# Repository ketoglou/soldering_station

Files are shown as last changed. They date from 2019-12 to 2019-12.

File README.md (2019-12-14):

# Soldering_station
A personal soldering station for Hakko 907 in Greek language but it can be easily adapted to any language.\
The following image shows the Temperature(red line) vs Resistance(blue line) chart of Hakko 907.\
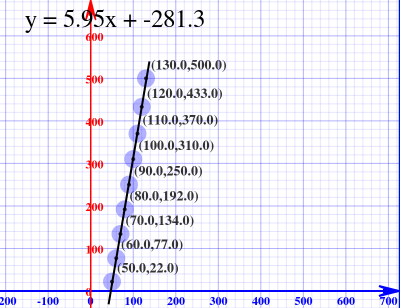
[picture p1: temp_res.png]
 \
The equation that is used to calculate temperature is based in least squares method and \
it is the following : Temperature = 5.95 * Resistance - 281.3.

- PCB.zip : Contains gerber files for PCB.
- Firmware : Contains PIC18F27K42 firmware.

The following image shows the PCB.\
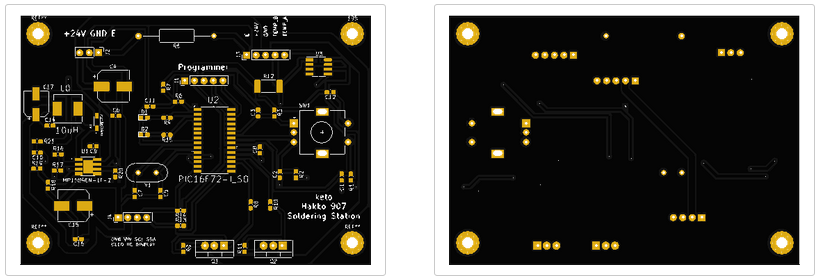
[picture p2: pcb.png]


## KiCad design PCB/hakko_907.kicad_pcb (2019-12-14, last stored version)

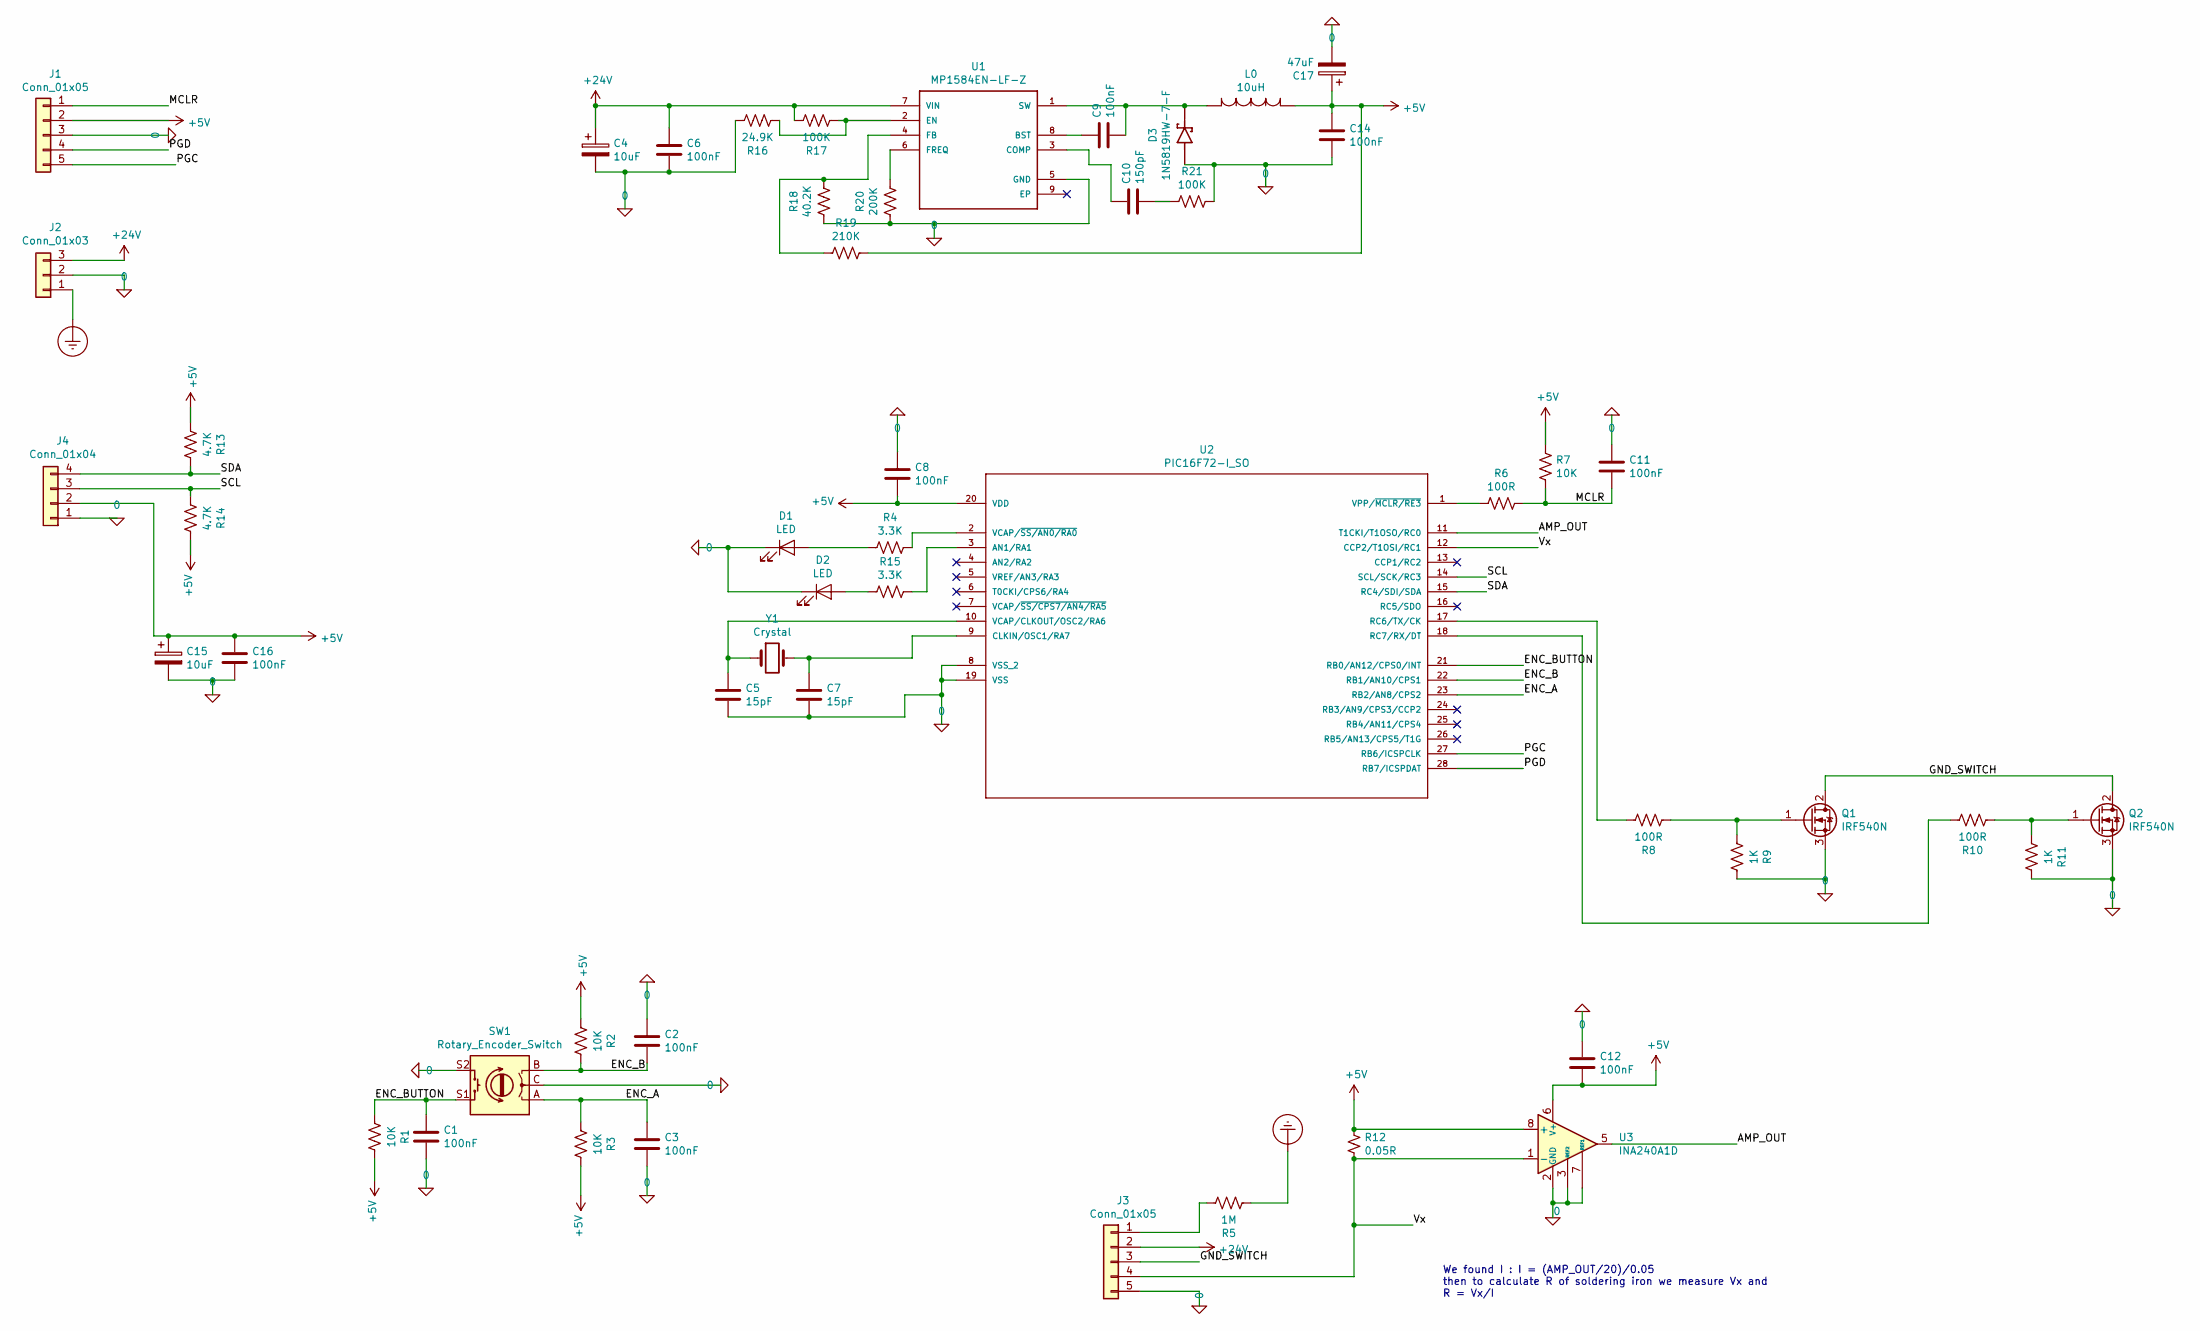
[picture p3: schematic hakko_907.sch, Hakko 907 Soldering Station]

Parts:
C1, C2, C3, C6, C8, C9, C11, C12, C14, C16: 100nF; C_0603_1608Metric_Pad1.05x0.95mm_HandSolder
C4, C15: 10uF; CP_Elec_8x6.2
C5, C7: 15pF; C_0603_1608Metric_Pad1.05x0.95mm_HandSolder
C10: 150pF; C_0603_1608Metric_Pad1.05x0.95mm_HandSolder
C17: 47uF; CP_Elec_6.3x5.9
D1, D2: LED; LED_0603_1608Metric_Pad1.05x0.95mm_HandSolder
D3: 1N5819HW-7-F; SOD3715X145N
J1, J3: Conn_01x05; PinHeader_1x05_P2.54mm_Vertical
J2: Conn_01x03; PinHeader_1x03_P2.54mm_Vertical
J4: Conn_01x04; PinHeader_1x04_P2.54mm_Vertical
L0: 10uH; INDM7676X355N
Q1, Q2: IRF540N; TO-220-3_Vertical
R1, R2, R3, R7: 10K; R_0603_1608Metric_Pad1.05x0.95mm_HandSolder
R4, R15: 3.3K; R_0603_1608Metric_Pad1.05x0.95mm_HandSolder
R5: 1M; R_Axial_DIN0309_L9.0mm_D3.2mm_P20.32mm_Horizontal
R6, R8, R10: 100R; R_0603_1608Metric_Pad1.05x0.95mm_HandSolder
R9, R11: 1K; R_0603_1608Metric_Pad1.05x0.95mm_HandSolder
R12: 0.05R; R_2512_6332Metric_Pad1.52x3.35mm_HandSolder
R13, R14: 4.7K; R_0603_1608Metric_Pad1.05x0.95mm_HandSolder
R16: 24.9K; R_0603_1608Metric_Pad1.05x0.95mm_HandSolder
R17, R21: 100K; R_0603_1608Metric_Pad1.05x0.95mm_HandSolder
R18: 40.2K; R_0603_1608Metric_Pad1.05x0.95mm_HandSolder
R19: 210K; R_0603_1608Metric_Pad1.05x0.95mm_HandSolder
R20: 200K; R_0603_1608Metric_Pad1.05x0.95mm_HandSolder
SW1: Rotary_Encoder_Switch; RotaryEncoder_Alps_EC11E-Switch_Vertical_H20mm
U1: MP1584EN-LF-Z; SOIC127P600X170-9N
U2: PIC16F72-I_SO; SOIC127P1030X265-28N
U3: INA240A1D; SOIC-8_3.9x4.9mm_P1.27mm
Y1: Crystal; Crystal_HC49-4H_Vertical

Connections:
0: C1.2, C2.1, C3.2, C4.2, C5.2, C6.2, C7.2, C8.1, C11.1, C12.1, C14.2, C15.2, C16.2, C17.2, D1.1 (K), D2.1 (K), D3.A, J1.3, J2.2, J3.5, J4.1, Q1.3 (S), Q2.3 (S), R9.1, R11.1, R16.1, R18.2, R20.2, R21.1, SW1.C, SW1.S2, U1.5 (GND), U2.8 (VSS_2), U2.19 (VSS), U3.2 (GND), U3.3 (REF2), U3.4 (GND), U3.7 (REF1)
+5V: C8.2, C12.2, C14.1, C15.1, C16.1, C17.1, J1.2, J4.2, L0.1, R1.1, R2.2, R3.1, R7.1, R12.1, R13.2, R14.1, R19.1, U2.20 (VDD), U3.6 (V+), U3.8 (+)
+24V: C4.1, C6.1, J2.3, J3.2, R17.1, U1.7 (VIN)
/AMP_OUT: U2.11 (T1CKI/T1OSO/RC0), U3.5
/ENC_A: C3.1, R3.2, SW1.A, U2.23 (RB2/AN8/CPS2)
/ENC_B: C2.2, R2.1, SW1.B, U2.22 (RB1/AN10/CPS1)
/ENC_BUTTON: C1.1, R1.2, SW1.S1, U2.21 (RB0/AN12/CPS0/INT)
/GND_SWITCH: J3.3, Q1.2 (D), Q2.2 (D)
/MCLR: C11.2, J1.1, R6.1, R7.2
/PGC: J1.5, U2.27 (RB6/ICSPCLK)
/PGD: J1.4, U2.28 (RB7/ICSPDAT)
/SCL: J4.3, R14.2, U2.14 (SCL/SCK/RC3)
/SDA: J4.4, R13.1, U2.15 (RC4/SDI/SDA)
/Vx: J3.4, R12.2, U2.12 (CCP2/T1OSI/RC1), U3.1 (-)
Earth_Protective: J2.1, R5.2
unnamed: C5.1, U2.10 (VCAP/CLKOUT/OSC2/RA6), Y1.1
unnamed: C7.1, U2.9 (CLKIN/OSC1/RA7), Y1.2
unnamed: C9.1, U1.8 (BST)
unnamed: C9.2, D3.C (K), L0.2, U1.1 (SW)
unnamed: C10.1, U1.3 (COMP)
unnamed: C10.2, R21.2
unnamed: D1.2 (A), R4.2
unnamed: D2.2 (A), R15.2
unnamed: J3.1, R5.1
unnamed: Q1.1 (G), R8.2, R9.2
unnamed: Q2.1 (G), R10.2, R11.2
unnamed: R4.1, U2.2 (VCAP/~SS/AN0/RA0)
unnamed: R6.2, U2.1 (VPP/~MCLR/RE3)
unnamed: R8.1, U2.17 (RC6/TX/CK)
unnamed: R10.1, U2.18 (RC7/RX/DT)
unnamed: R15.1, U2.3 (AN1/RA1)
unnamed: R16.2, R17.2, U1.2 (EN)
unnamed: R18.1, R19.2, U1.4 (FB)
unnamed: R20.1, U1.6 (FREQ)

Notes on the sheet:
We found I : I = (AMP_OUT/20)/0.05 then to calculate R of soldering iron we measure Vx and R = Vx/I

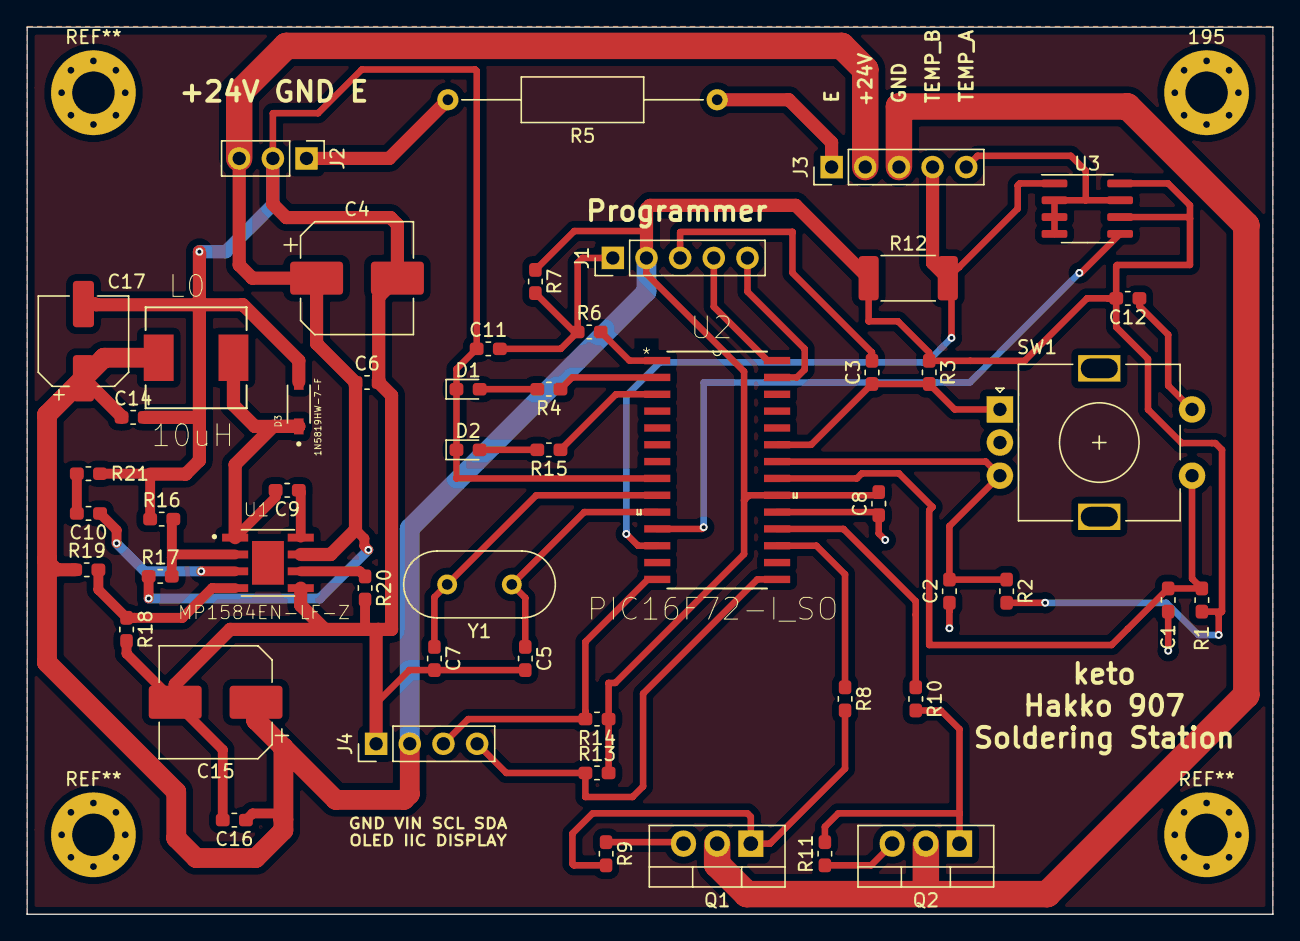
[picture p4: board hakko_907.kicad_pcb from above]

Board: 2 copper layers, 94.0 x 66.9 mm, 53 parts (0 on the bottom side), 34 nets.

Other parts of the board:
195: MountingHole_3.2mm_M3_Pad_Via

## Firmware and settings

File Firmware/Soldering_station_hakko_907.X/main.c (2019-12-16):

/*
 * File:   main.c
 * Author: orion
 *
 * Created on October 25, 2019, 9:03 PM
 */

/* EEPROM:
 * ADDRESS: 0                   1
 * DATA   : HIGH_BYTE_OLD_TEMP  LOW_BYTE_OLD_TEMP
 */

//Includes
#include <xc.h>
#include <pic18f27k42.h>
#include "config.h"
#include "i2c.h"
#include "oled_sdd1306.h"
#include "init_strings.h"

// This code is meant to run on a PIC running at 64 MHz.
#define _XTAL_FREQ 64000000
#define byte unsigned char
#define LED_STAT LATAbits.LA0
#define LED_READY LATAbits.LA1
#define MOSFET1 LATCbits.LC6
#define MOSFET2 LATCbits.LC7

//Define functions
void timer0_init(void);
void external_interrupt_init(void);
void write_eeprom(byte data,byte address[2]); //address[0]=high byte of address,address[1]=low byte of address
byte read_eeprom(byte address[2]);
void timer2PWM_init(void);
void ADC_Init(void);
void ADC_Start(byte pin);

//Define variables
int seconds_passed;
//byte max6675_read; //MAX6675 could not be expected to produce more than about 5 reads per second.
int set_temp = 180;
byte set_temperature[3];
byte real_temperature[3];
byte temp_change = 1;
int old_temp = 0;
byte eeprom_address[2];
int real_temp = 0;
int temporary_val; //temporary value
float dV,dV_average,Current,Vx,Vx_average,R,Temp;
byte measure_flag = 0;
byte timer2_pwm_counter = 0;
byte pulse_width;
int adc_result;
byte adc_flag;
//byte max6675_counter = 0;
CHAR detached_str[3] = {PAVLA,PAVLA,PAVLA};

//------------------------------------------------------------------------------
void __interrupt(irq(IRQ_TMR0)) TIMER0_ISR(void){
    TMR0L= 0xDB;
    TMR0H= 0x0B;
    seconds_passed++;
    measure_flag++;
    //max6675_read =1;
    LED_STAT = !LED_STAT;
    //if 10 minutes passed lower the temperature
    if(seconds_passed == 600){
        old_temp = set_temp;
        set_temp = 180;
        temp_change = 1;
    }else if(seconds_passed == 1800){ //if 30 minutes passed zero the temperature
        set_temp = 0;
        seconds_passed = 0;
        T0CON0bits.EN = 0; //Disable timer
        LED_STAT = 0;
        temp_change = 1;
    }
    PIR3bits.TMR0IF = 0; //Clear interrupt flag
}

//Period:0.01sec
//Interupt:0.0001sec
void __interrupt(irq(IRQ_TMR2)) TIMER2_ISR(void){
    timer2_pwm_counter++;
    if(timer2_pwm_counter >= pulse_width){
        MOSFET1 = 0;
        MOSFET2 = 0;
    }else{
        MOSFET1 = 1;
        MOSFET2 = 1;
    }
    if(timer2_pwm_counter == 100){
        timer2_pwm_counter = 0;
        MOSFET1 = 1;
        MOSFET2 = 1;
    }
    PIR4bits.TMR2IF = 0; //Clear interrupt flag
}

void __interrupt(irq(IRQ_AD)) ADC_ISR(void){
    adc_result = ADRESL;
    adc_result = adc_result | (ADRESH <<8);
    adc_flag = 1;
    PIR1bits.ADIF = 0; //Clear interrupt flag
}

void __interrupt(irq(IRQ_INT0)) INT0_ISR(void){
    if(!T0CON0bits.EN){
        set_temp = old_temp;
        T0CON0bits.EN = 1;
        temp_change = 1;
    }else if(set_temp == 180 && seconds_passed > 600){
        set_temp = old_temp;
        temp_change = 1;
    }
    seconds_passed = 0;
    PIR1bits.INT0IF = 0;
}

void __interrupt(irq(IRQ_INT1)) INT1_ISR(void){
    PIE7bits.INT2IE = 0;
    PIR7bits.INT2IF = 0;
    if((set_temp == 180 && seconds_passed > 600)|| !T0CON0bits.EN){
        set_temp = old_temp;
        if(!T0CON0bits.EN)
            T0CON0bits.EN = 1; //Enable timer
    }
    if(set_temp < 500)
        set_temp++;
    temp_change = 1;
    seconds_passed = 0;
    PIE5bits.INT1IE = 0;
    PIR5bits.INT1IF = 0;
}

void __interrupt(irq(IRQ_INT2)) INT2_ISR(void){
    PIE5bits.INT1IE = 0;
    PIR5bits.INT1IF = 0;
    if((set_temp == 180 && seconds_passed > 600)|| !T0CON0bits.EN){
        set_temp = old_temp;
        if(!T0CON0bits.EN)
            T0CON0bits.EN = 1; //Enable timer
    }
    if(set_temp > 180)
        set_temp--; 
    temp_change = 1;
    seconds_passed = 0;
    PIE7bits.INT2IE = 0;
    PIR7bits.INT2IF = 0;
}

void __interrupt(irq(IRQ_NVM)) EEPROM_ISR(void){
    NVMCON1bits.WREN = 0; //Disable writes
    PIR0bits.NVMIF = 0;
}

void __interrupt(irq(IRQ_I2C1TX)) I2C_TX_ISR(void){
    I2C1TXB = I2C_TX_BUFFER[I2C_TX_COUNTER];
    I2C_TX_COUNTER ++;
}

void __interrupt(irq(IRQ_I2C1RX)) I2C_RX_ISR(void){
    I2C_RX_BUFFER[I2C_RX_COUNTER] = I2C1RXB;
    I2C_RX_COUNTER ++;
}

void __interrupt(irq(IRQ_I2C1)) I2C_GENERAL_ISR(void){
    if(I2C1PIRbits.PC1IF)
        I2C_STOP_DETECTED = 1;
    I2C1PIR = 0x00;
}

void __interrupt(irq(default)) DEFAULT_ISR(void){
    //Unhandled interrupts go here
    Reset(); //In normal conditions we will never come here
}

//------------------------------------------------------------------------------
void main(void) {
    //Oscillator Configuration(We use crystal oscillator)
    OSCCON1 = 0x20; //ExtOSC with 4xPLL
    OSCCON2 = 0x20;
    OSCCON3 = 0x00;
    OSCEN = 0x80;
    while(!OSCSTATbits.EXTOR || !OSCSTATbits.PLLR);
    
    //IVTBASE* Registers must change if we use multiple IVTs(bootloader for instance)
    /*IVTBASEU = 0x00;
    IVTBASEH = 0x00;
    IVTBASEL = 0x00;*/
    IVTLOCK = 0x01; //IVTBASE Registers are locked and cannot be written(IVTWAY=1)
    
    //PPS Configuration
    PPSLOCKbits.PPSLOCKED = 0; //PPS selections
    
    ANSELC = 0x00;
    TRISAbits.TRISA0 = 0; //LED STATUS
    TRISAbits.TRISA1 = 0; //LED READY
    TRISCbits.TRISC0 = 1; //Amplifier Input
    ANSELCbits.ANSELC0 = 1; //Read Analog Amplifier
    TRISCbits.TRISC1 = 1; //Vx Input
    ANSELCbits.ANSELC1 = 1; //Read Analog Vx
    TRISCbits.TRISC6 = 0;
    TRISCbits.TRISC7 = 0;
    
    INTCON0bits.IPEN = 1; //Enable interrupt priority
    INTCON0bits.GIEH = 1; //Enable high priority interrupts
    INTCON0bits.GIEL = 1; //Enable low priority interrupts
    
    external_interrupt_init();
    I2C_Init();
    //SPI1_Init();
    ADC_Init();
    OLED_Init();
    timer0_init();
    timer2PWM_init();
    
    PPSLOCKbits.PPSLOCKED = 1; //PPS selections
    
    //WatchDog Configuration,no Window 
    WDTCON1 = 0x07; //LFINTOSC used,Windows is open at 100% of time
    WDTCON0 = 0x1B; //32 seconds watchdog time,Enable watchdog
    
    //Initialize screen display
    OLED_WriteString(keto_st,12,0,OLED_POSITION);
    OLED_WriteNumber(hakko_num,3,0,OLED_POSITION);
    OLED_WriteString(sold_station,16,1,0);
    OLED_WriteString(temperature,12,3,0);
    OLED_WriteString(set,11,5,0);
    OLED_WriteString(real,11,6,0);
    OLED_WriteString(celsious,2,5,112);
    OLED_WriteString(celsious,2,6,112);
    
    //Get previous temperature
    eeprom_address[0] = 0x00; //Address high byte
    eeprom_address[1] = 0x00; //Address low byte
    set_temp = read_eeprom(eeprom_address) << 8;
    eeprom_address[1] = 0x01; //Address low byte
    set_temp = set_temp | read_eeprom(eeprom_address);
    if(set_temp < 180)
        set_temp = 180;
    
    MOSFET1 = 1;
    MOSFET2 = 1;
    
    while(1){
        //Calculate encoder (set temperature)
        if(temp_change){
            temporary_val = set_temp/100;
            set_temperature[0] = temporary_val;
            temporary_val = (set_temp-temporary_val*100)/10;
            set_temperature[1] = temporary_val;
            temporary_val = set_temp-(set_temp/100)*100-temporary_val*10;
            set_temperature[2] = temporary_val;
            OLED_WriteNumber(set_temperature,3,5,88);
            //Write to EEPROM
            eeprom_address[0] = 0x00; //Address high byte
            eeprom_address[1] = 0x00; //Address low byte
            temporary_val = set_temp >> 8; //High temp byte
            write_eeprom(temporary_val,eeprom_address);
            temporary_val = set_temp; //Low temp byte
            eeprom_address[1] = 0x01; //Address low byte
            write_eeprom(temporary_val,eeprom_address);
            
            while(!PORTBbits.RB1 || !PORTBbits.RB2); //Wait here to suspend any voltage spikes from encoder
            
            temp_change = 0;
            PIR5bits.INT1IF = 0;
            PIR7bits.INT2IF = 0;
            PIE5bits.INT1IE = 1;
            PIE7bits.INT2IE = 1;
        }
        /*
         //Thermocouple Hakko 907 soldering iron
         if(!PIE2bits.SPI1RXIE && max6675_read){
            if(flag_detached){
                OLED_WriteString(detached_str,3,6,88);
                max6675_counter = 0;
            }else{
                if(!max6675_counter){
                    real_temp = 0.5+((float)spi_temperature*0.25);
                    max6675_counter = 1;
                }else if(max6675_counter){
                    real_temp = real_temp + (0.5+((float)spi_temperature*0.25));
                    real_temp = real_temp/2;
                    temporary_val = real_temp/100;
                    real_temperature[0] = temporary_val;
                    temporary_val = (real_temp-temporary_val*100)/10;
                    real_temperature[1] = temporary_val;
                    temporary_val = real_temp-(real_temp/100)*100-temporary_val*10;
                    real_temperature[2] = temporary_val;
                    OLED_WriteNumber(real_temperature,3,6,88);
                    max6675_counter = 0;
                }
            }
            SPI1_Master_RecieveOnly();
            max6675_read = 0;
        }*/
        
        //Thermistor Hakko 907 soldering iron
        //Calculate Temperature
        if(measure_flag == 2){
            //Measure current 10 times
            dV_average = 0;
            for(byte i=0;i<200;i++){
                while(ADCON0bits.GO);
                ADC_Start(0x10); //RC0=Amplifier Voltage
                while(!adc_flag);//Wait if an ADC process is still processing
                dV = adc_result * 0.00122; //Real voltage real
                dV = dV/20.0; //Because is amplified by x20 
                dV_average = dV_average + dV;
            }
            dV_average = dV_average/200;
            Current = dV_average/0.05; //Current across 0.05 Ohm resistance
            if(Current != 0){
                Vx_average = 0;
                for(byte i=0;i<10;i++){
                    while(ADCON0bits.GO);
                    ADC_Start(0x11); //RC1=Vx Voltage
                    while(!adc_flag);//Wait if an ADC process is still processing  
                    Vx = adc_result * 0.00122; //Real voltage real
                    Vx_average = Vx_average + Vx;
                }
                Vx_average = Vx_average/10;
                R = Vx_average/Current;
            }else
                R = 0;
            if(R > 48 && R < 200){
                Temp = 5.95*R - 281.3; //Based in least squares
                real_temp = (int)Temp;
                temporary_val = real_temp/100;
                real_temperature[0] = temporary_val;
                temporary_val = (real_temp-temporary_val*100)/10;
                real_temperature[1] = temporary_val;
                temporary_val = real_temp-(real_temp/100)*100-temporary_val*10;
                real_temperature[2] = temporary_val;
                OLED_WriteNumber(real_temperature,3,6,88);
            }else{
                OLED_WriteString(detached_str,3,6,88);
            }
            measure_flag = 0;
        }
        
        //Calculate Pulse
        if(set_temp > real_temp && (set_temp - real_temp) > 20)
            pulse_width = 40;
        else if(set_temp > real_temp)
            pulse_width = (((set_temp - real_temp)*25)/20)+5;
        else
            pulse_width = 4; 
        
        //READY LED
        if(set_temp > real_temp && (set_temp-real_temp) < 10)
            LED_READY = 1;
        else if(set_temp < real_temp && (real_temp-set_temp) < 10)
            LED_READY = 1;
        else if(set_temp == real_temp)
            LED_READY = 1;
        else
            LED_READY = 0;
        CLRWDT(); //Clear Watchdog timer
    }
}

//------------------------------------------------------------------------------

//********Timer functions*******************************************************
void timer0_init(void){
    T0CON0 = 0x10;
    T0CON1 = 0x48;
    TMR0L= 0xDB;
    TMR0H= 0x0B;
    seconds_passed = 0;
    IPR3bits.TMR0IP = 0; //Low priority interrupt
    PIR3bits.TMR0IF = 0; //Clear interrupt flag
    PIE3bits.TMR0IE = 1; //Enable interrupt
    T0CON0bits.EN = 1;
}
//--------------------------------PWM-------------------------------------------

//Period:0.001sec
//Interupt:0.0001sec
void timer2PWM_init(void){
    TRISCbits.TRISC6 = 0; //MOSFET1 -> PWM5
    TRISCbits.TRISC7 = 0; //MOSFET2 -> PWM6
    ANSELCbits.ANSELC6 = 0;
    ANSELCbits.ANSELC7 = 0;
    
    T2CON= 0x60; //Prescale:64,Postscale:1
    T2PR = 25;
    T2CLK = 0x01; //CLK = Fosc/4 = 16MHz
    T2HLT = 0x00;
    IPR4bits.TMR2IP = 1; //High priority interrupt
    PIR4bits.TMR2IF = 0; //Clear interrupt flag
    PIE4bits.TMR2IE = 1; //Enable interrupt
    T2CONbits.ON = 1;
}

//------------------------------------------------------------------------------
void external_interrupt_init(void){
    TRISBbits.TRISB0 = 1;
    TRISBbits.TRISB1 = 1;
    TRISBbits.TRISB2 = 1;
    ANSELBbits.ANSELB0 = 0;
    ANSELBbits.ANSELB1 = 0;
    ANSELBbits.ANSELB2 = 0;
    
    //INTxPPS SELECT EXTERNAL INTERRUPT PIN
    INT0PPS = 0x08;
    INT1PPS = 0x09;
    INT2PPS = 0x0A;
    
    INTCON0bits.INT0EDG = 0; //Interrupt on falling edge of INT0 pin
    INTCON0bits.INT1EDG = 0; //Interrupt on falling edge of INT1 pin
    INTCON0bits.INT2EDG = 0; //Interrupt on falling edge of INT2 pin
    
    IPR1bits.INT0IP = 1; //High priority interrupt
    IPR5bits.INT1IP = 1; //High priority interrupt
    IPR7bits.INT2IP = 1; //High priority interrupt
    PIR1bits.INT0IF = 0; //Clear interrupt flag
    PIR5bits.INT1IF = 0; //Clear interrupt flag
    PIR7bits.INT2IF = 0; //Clear interrupt flag
    PIE1bits.INT0IE = 1; //Enable interrupt
    PIE5bits.INT1IE = 1; //Enable interrupt
    PIE7bits.INT2IE = 1; //Enable interrupt
}

//------------------------------------------------------------------------------
void write_eeprom(byte data,byte address[2]){
    
    NVMCON1 = 0x00; //Access EEPROM memory locations,set REG bits to 00
    
    while(NVMCON1bits.WR); //Wait if we still write
    PIR0bits.NVMIF = 0; //Clear flag
    IPR0bits.NVMIP = 1; //High priority
    
    NVMADRH = 0x03 & address[0];
    NVMADRL = address[1];
    NVMDAT = data;
    
    NVMCON1bits.WREN = 1; //Enable writes
    INTCON0bits.GIE = 0; //Disable interrupts
    
    //Required unlock sequence
    NVMCON2 = 0x55;
    NVMCON2 = 0xAA;
   
    NVMCON1bits.WR = 1; //Set WR bit to begin write  
    PIE0bits.NVMIE = 1; //Enable NVM interrupt
    INTCON0bits.GIE = 1; //Enable interrupts
}

byte read_eeprom(byte address[2]){
    byte temp;
    NVMCON1 = 0x00; //Access EEPROM memory locations,set REG bits to 00

    NVMADRH = 0x03 & address[0];
    NVMADRL = address[1];
    
    NVMCON1bits.RD = 1; //Read data
    temp = NVMDAT;
    return temp;
}

//------------------------ADC Functions-----------------------------------------

void ADC_Init(void){
    //Voltage measure
    ADCON0 = 0x94;
    ADCON1 = 0x00;
    ADCON2 = 0x00;
    ADREF = 0x00; //VDD,VSS as references
    IPR1bits.ADIP = 0; //Low priority
    PIE1bits.ADIE = 1; //Enable interrupt
    PIR1bits.ADIF = 0; //Clear interrupt flag
}

//0-7 =RA0-RA7,8-15=RB0-RB7,16-23=RC0-RC7
void ADC_Start(byte pin){
    if(!ADCON0bits.GO){
        ADPCH = pin;
        adc_result = 0;
        adc_flag = 0;
        ADCON0bits.GO = 1;
    }
}

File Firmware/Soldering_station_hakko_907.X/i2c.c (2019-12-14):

#include <xc.h>
#include "i2c.h"

void I2C_Init(void){
    //Configure SDA,SCL Pins
    I2C1CON0bits.EN = 0; //Disable I2C module
    TRISCbits.TRISC3 = 0; //SCL
    TRISCbits.TRISC4 = 0; //SDA
    LATCbits.LATC3 = 0; // Clear PORTC write latches
    LATCbits.LATC4 = 0;
    ANSELCbits.ANSELC3 = 0; //RC3 clear analog
    ANSELCbits.ANSELC4 = 0; //RC4 clear analog
    ODCONCbits.ODCC3 = 1; //RC3 as open-drain
    ODCONCbits.ODCC4 = 1; //RC4 as open-drain
    RC3I2C = 0x21;// Standard GPIO slew rate,Internal pull-ups x10,I2C specific thresholds
    RC4I2C = 0x21;
    WPUC = 0x18; //RC3,RC4 pull up enabled
    SLRCONCbits.SLRC3 = 0; // No slew rate limiting
    SLRCONCbits.SLRC4 = 0;
    I2C1SCLPPS = 0x13; //RC3 PPS Input
    I2C1SDAPPS = 0x14; //RC4 PPS Input
    RC3PPS = 0x21; //RC3 PPS Output
    RC4PPS = 0x22; //RC4 PPS Output
    
    I2C1CON0 = 0x04;
    I2C1CON1 = 0x80;
    I2C1CON2 = 0x24; //I2C Clock = I2C1CLK(500kHz)/4 = 125kHz
    I2C1CLK = 0x03; //MFINTOSC as clock (500kHz)
    I2C1CNT = 0;
           
    I2C1PIR = 0x00;
    I2C1ERR = 0x00; 
    
    I2C_STOP_DETECTED = 1;
    
    IPR3bits.I2C1TXIP = 0; //Transmit interrupt low priority
    IPR2bits.I2C1RXIP = 0; //Receive interrupt low priority
    PIR3bits.I2C1TXIF = 0; //Transmit interrupt flag clear
    PIR2bits.I2C1RXIF = 0; //Receive interrupt flag clear
    PIE3bits.I2C1TXIE = 1; //Transmit interrupt enable
    PIE2bits.I2C1RXIE = 1; //Receive interrupt enable
    
    //General interrupts
    I2C1PIRbits.PC1IF = 0;//Clear STOP interrupt flag
    I2C1PIEbits.PC1IE = 1; //Enable STOP interrupt
    IPR3bits.I2C1IP = 0; //General interrupt low priority
    PIR3bits.I2C1IF = 0; //General interrupt flag clear
    PIE3bits.I2C1IE = 1; //General interrupt enable
    
    I2C1CON0bits.EN = 1; //Enable I2C module
}

unsigned char I2C_Transmit(byte *buffer,unsigned char buffer_size,byte address){
    if(I2C_STOP_DETECTED && I2C1STAT0bits.BFRE && I2C1CNT == 0){
        I2C_STOP_DETECTED = 0;
        for(unsigned char i=0;i<(buffer_size-1);i++){
            I2C_TX_BUFFER[i] =  buffer[i+1];
        }
        I2C1ADB1 = address;
        I2C1CNT = buffer_size;
        I2C1TXB = buffer[0];
        I2C_TX_COUNTER = 0;
        I2C1CON0bits.S = 1;
        return 1;
    }
    return 0;
}
